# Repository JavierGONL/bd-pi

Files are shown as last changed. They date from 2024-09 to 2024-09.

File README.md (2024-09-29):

# BD-π

------------
## integrantes: 
* Kevin Javier Gonzalez Luna
* David Alejandro Montes Rodrigrez
* Rafael David Martinez Ovallos
------------

<div align='center'>
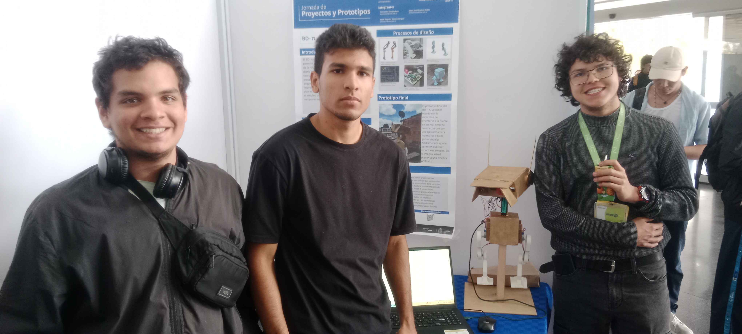
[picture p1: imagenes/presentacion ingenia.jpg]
<figure> </br>
<figcaption><b></b></figcaption></figure>
</div>

#### 🤖[wiki del proyecto](https://github.com/JavierGONL/bd-pi/wiki)🤖

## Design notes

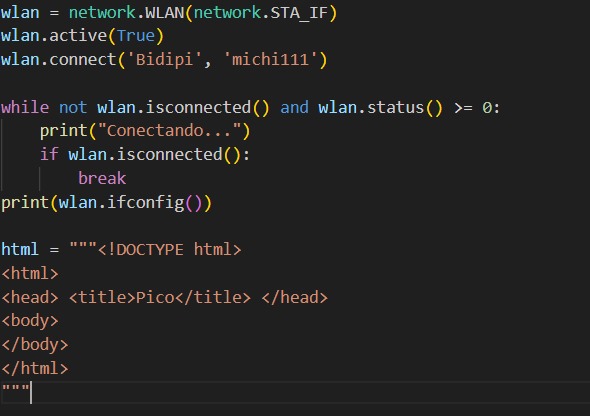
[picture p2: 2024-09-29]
imagenes/Código Wifi.jpg

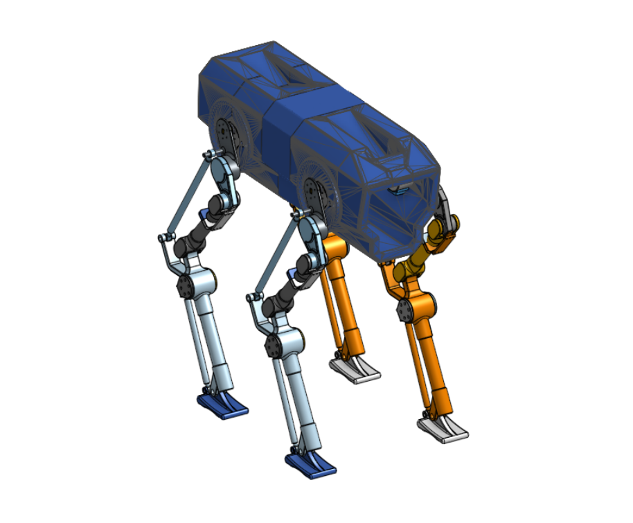
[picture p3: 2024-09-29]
imagenes/Primer modelo.png

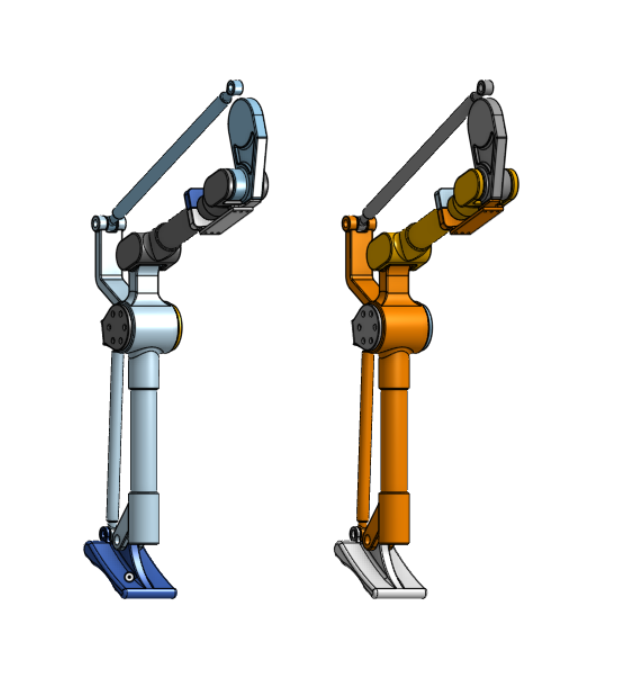
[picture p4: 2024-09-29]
imagenes/Patas Modeladas.png

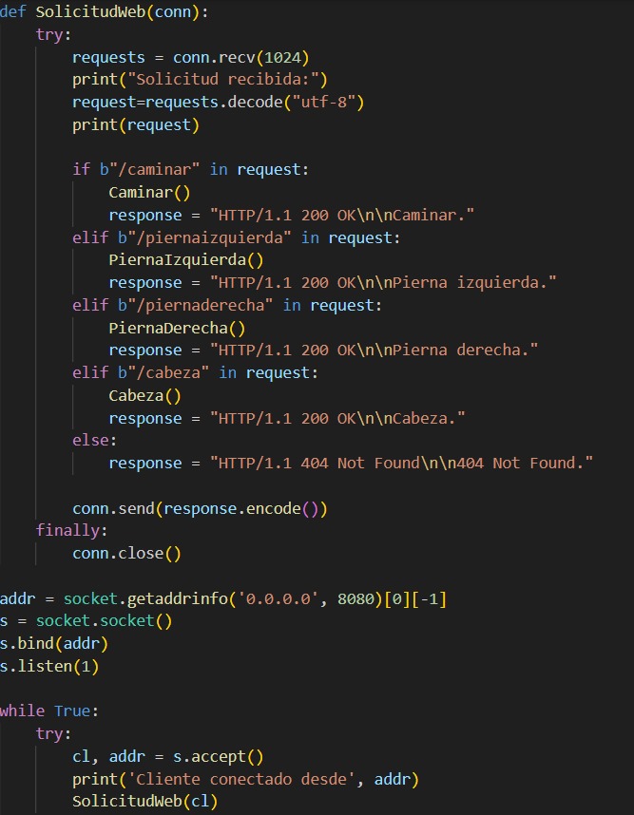
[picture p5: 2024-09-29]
imagenes/Imagen de WhatsApp 2024-09-25 a las 10.45.55_e9e9bb14.jpg

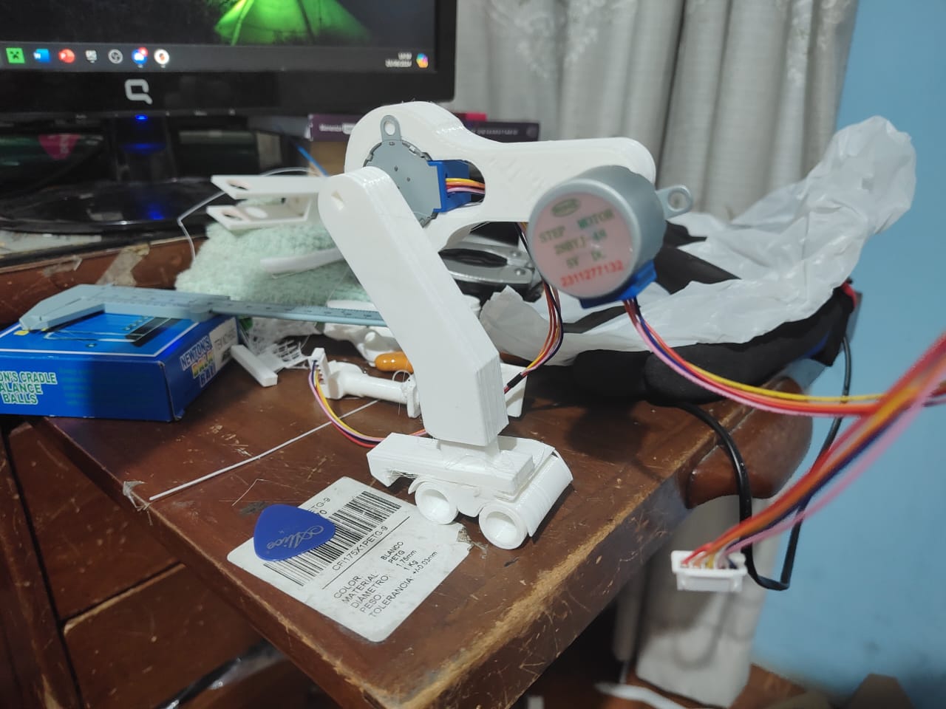
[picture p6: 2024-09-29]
imagenes/Idea Patines.jpg

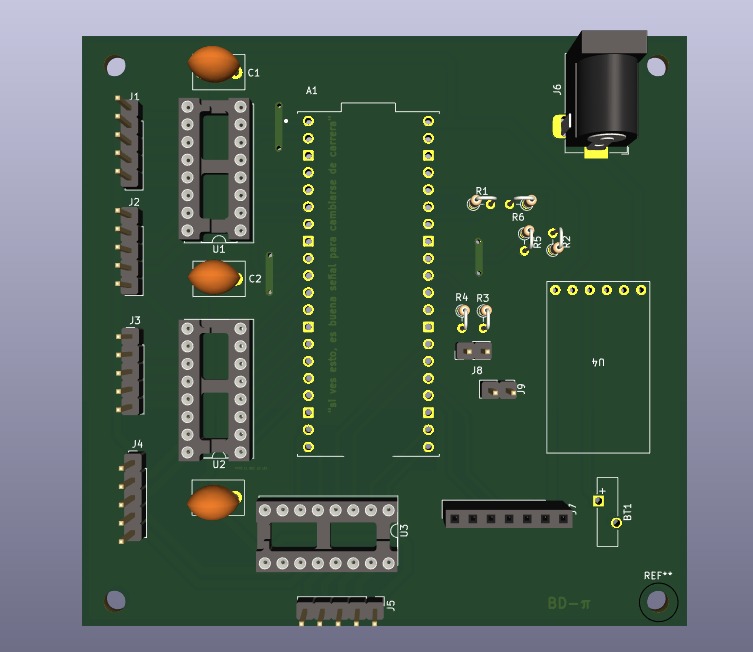
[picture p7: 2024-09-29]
imagenes/PCB 3D.jpg

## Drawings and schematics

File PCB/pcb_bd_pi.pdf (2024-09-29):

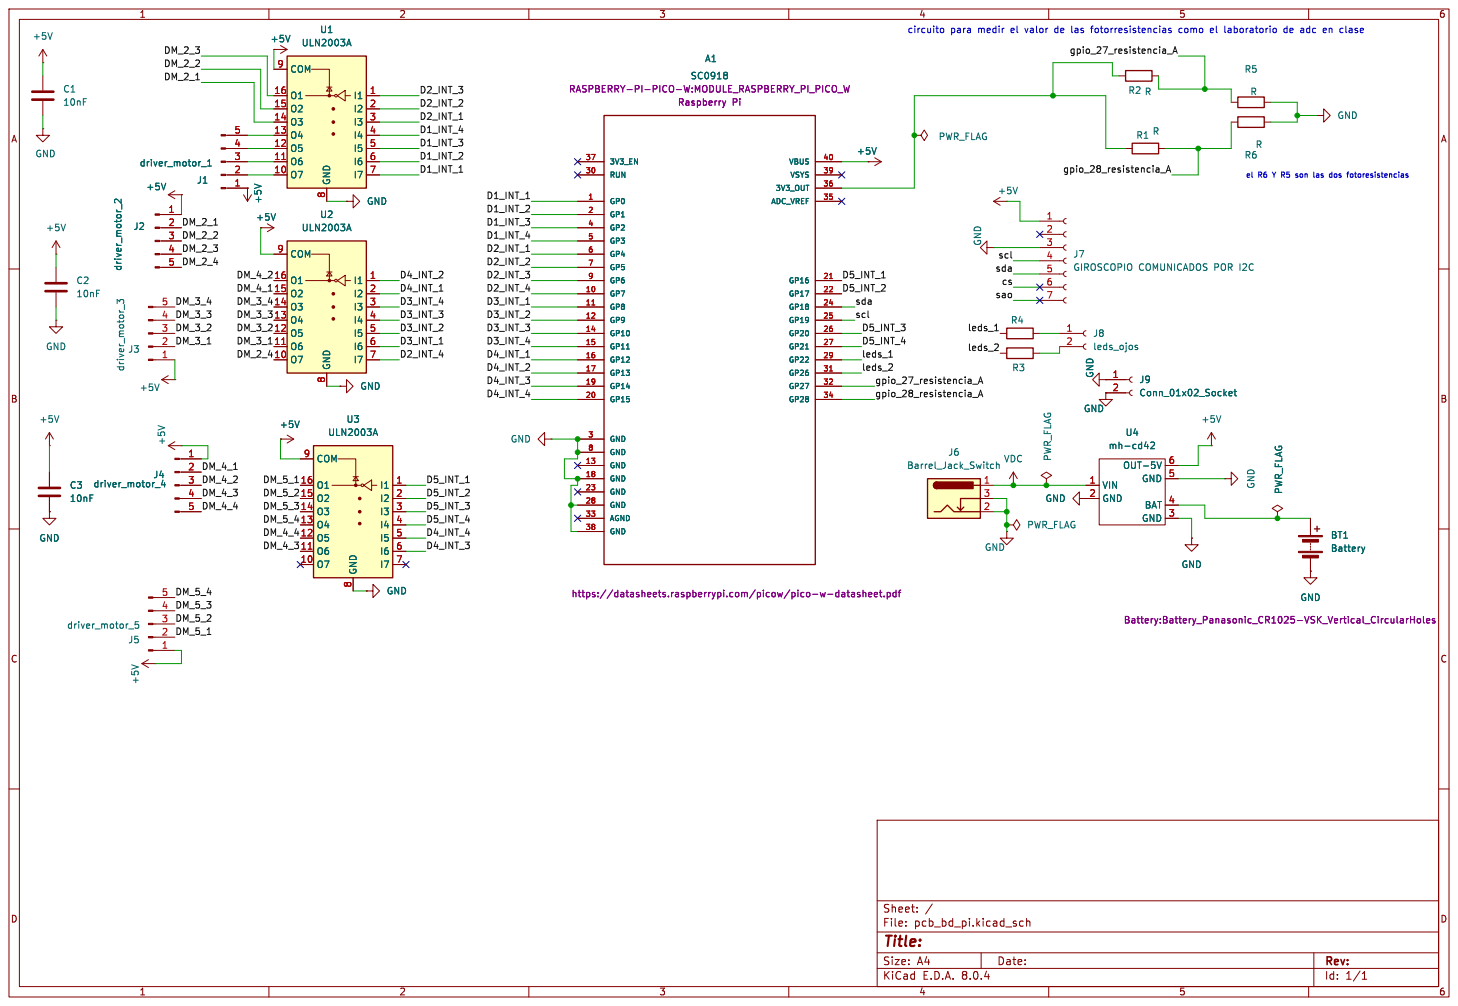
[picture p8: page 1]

Id: 1/1 Title: File: pcb_bd_pi.kicad_sch Sheet: / GND

https://datasheets.raspberrypi.com/picow/pico-w-datasheet.pdf

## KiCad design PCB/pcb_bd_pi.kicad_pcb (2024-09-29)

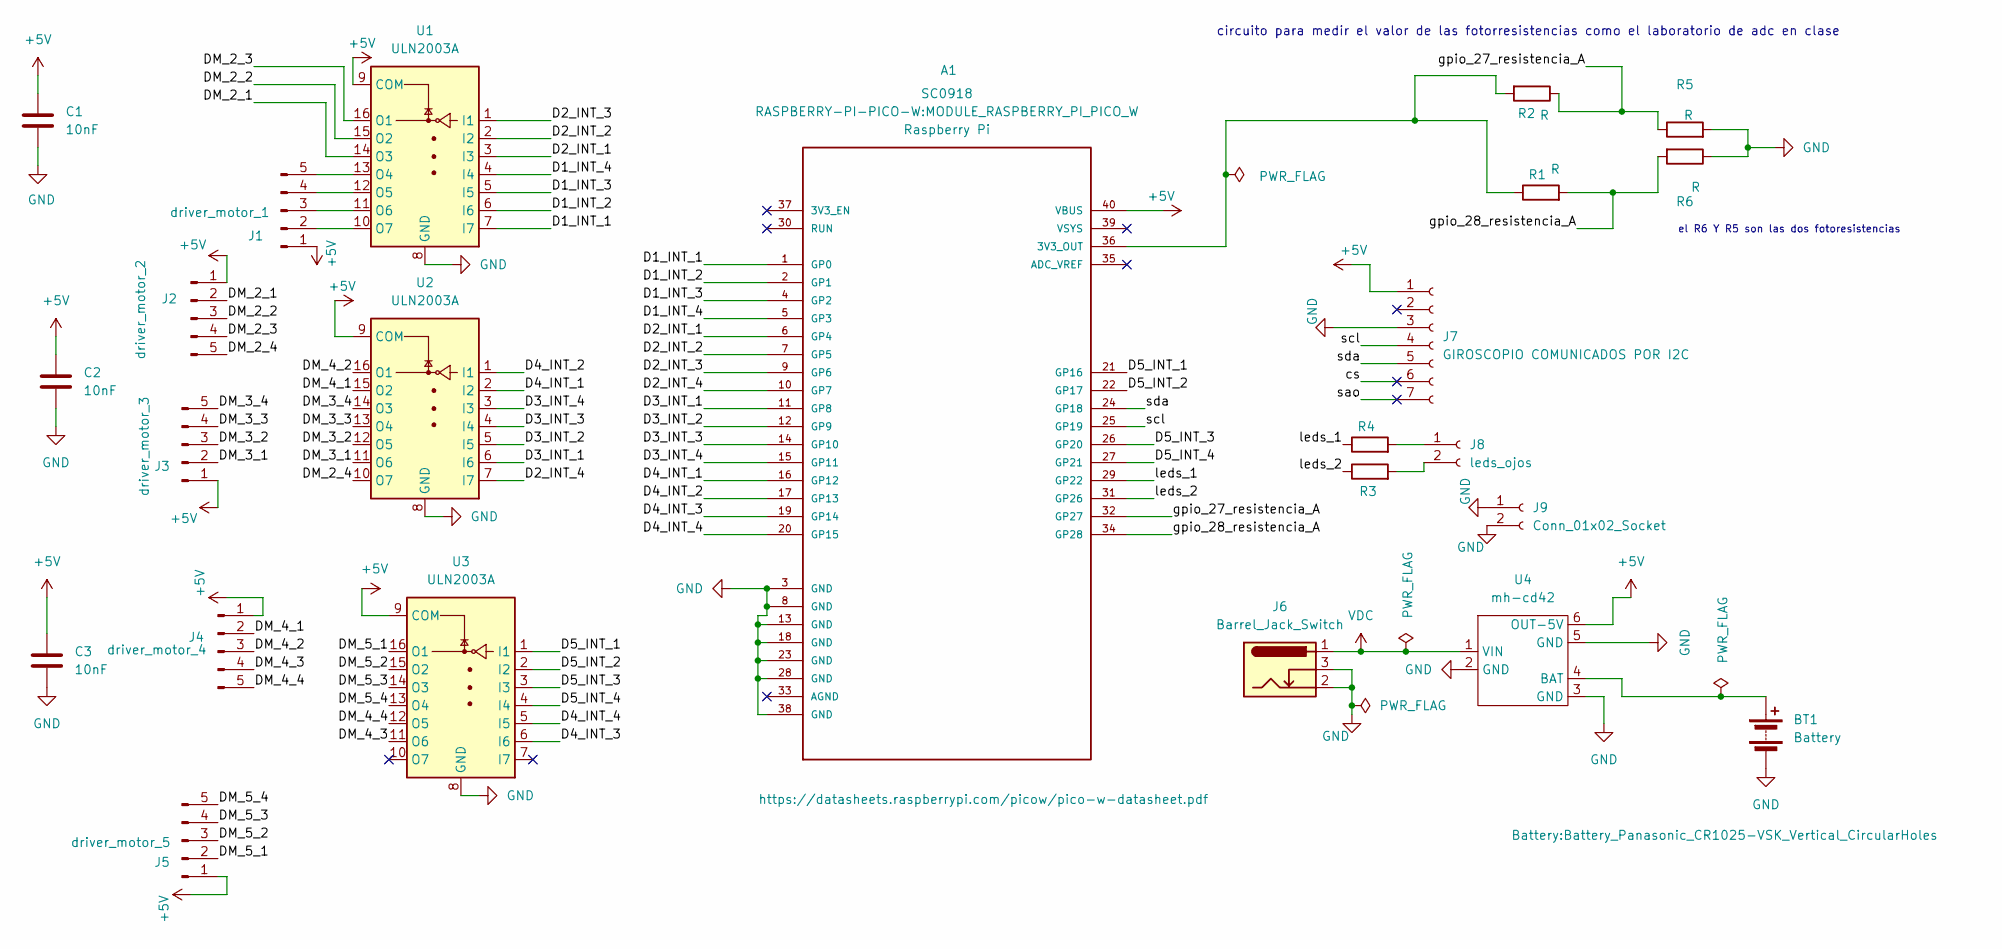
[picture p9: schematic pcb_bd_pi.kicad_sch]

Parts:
A1: SC0918; MODULE_RASPBERRY_PI_PICO_W; PARTREV 1.6
BT1: Battery; Battery_Panasonic_CR1025-VSK_Vertical_CircularHoles
C1, C2, C3: 10nF; C_Disc_D7.5mm_W5.0mm_P5.00mm
J1: driver_motor_1; PinHeader_1x05_P2.54mm_Vertical
J2: driver_motor_2; PinHeader_1x05_P2.54mm_Vertical
J3: driver_motor_3; PinHeader_1x05_P2.54mm_Vertical
J4: driver_motor_4; PinHeader_1x05_P2.54mm_Vertical
J5: driver_motor_5; PinHeader_1x05_P2.54mm_Vertical
J6: Barrel_Jack_Switch; BarrelJack_Horizontal
J7: GIROSCOPIO COMUNICADOS POR I2C; PinSocket_1x07_P2.54mm_Vertical
J8: leds_ojos; PinHeader_1x02_P2.54mm_Vertical
J9: Conn_01x02_Socket; PinHeader_1x02_P2.54mm_Vertical
R1, R2, R3, R4, R5, R6: R; R_Axial_DIN0204_L3.6mm_D1.6mm_P2.54mm_Vertical
U1, U2, U3: ULN2003A; DIP-16_W7.62mm_Socket
U4: mh-cd42

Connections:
+5V: A1.40 (VBUS), C1.1, C2.1, C3.1, J1.1, J2.1, J3.1, J4.1, J5.1, J7.1, U1.9 (COM), U2.9 (COM), U3.9 (COM), U4.6 (OUT-5V)
/D1_INT_1: A1.1 (GP0), U1.7 (I7)
/D1_INT_2: A1.2 (GP1), U1.6 (I6)
/D1_INT_3: A1.4 (GP2), U1.5 (I5)
/D1_INT_4: A1.5 (GP3), U1.4 (I4)
/D2_INT_1: A1.6 (GP4), U1.3 (I3)
/D2_INT_2: A1.7 (GP5), U1.2 (I2)
/D2_INT_3: A1.9 (GP6), U1.1 (I1)
/D2_INT_4: A1.10 (GP7), U2.7 (I7)
/D3_INT_1: A1.11 (GP8), U2.6 (I6)
/D3_INT_2: A1.12 (GP9), U2.5 (I5)
/D3_INT_3: A1.14 (GP10), U2.4 (I4)
/D3_INT_4: A1.15 (GP11), U2.3 (I3)
/D4_INT_1: A1.16 (GP12), U2.2 (I2)
/D4_INT_2: A1.17 (GP13), U2.1 (I1)
/D4_INT_3: A1.19 (GP14), U3.6 (I6)
/D4_INT_4: A1.20 (GP15), U3.5 (I5)
/D5_INT_1: A1.21 (GP16), U3.1 (I1)
/D5_INT_2: A1.22 (GP17), U3.2 (I2)
/D5_INT_3: A1.26 (GP20), U3.3 (I3)
/D5_INT_4: A1.27 (GP21), U3.4 (I4)
/DM_2_1: J2.2, U1.14 (O3)
/DM_2_2: J2.3, U1.15 (O2)
/DM_2_3: J2.4, U1.16 (O1)
/DM_2_4: J2.5, U2.10 (O7)
/DM_3_1: J3.2, U2.11 (O6)
/DM_3_2: J3.3, U2.12 (O5)
/DM_3_3: J3.4, U2.13 (O4)
/DM_3_4: J3.5, U2.14 (O3)
/DM_4_1: J4.2, U2.15 (O2)
/DM_4_2: J4.3, U2.16 (O1)
/DM_4_3: J4.4, U3.11 (O6)
/DM_4_4: J4.5, U3.12 (O5)
/DM_5_1: J5.2, U3.16 (O1)
/DM_5_2: J5.3, U3.15 (O2)
/DM_5_3: J5.4, U3.14 (O3)
/DM_5_4: J5.5, U3.13 (O4)
/cs: J7.6
/gpio_27_resistencia_A: A1.32 (GP27), R2.1, R5.1
/gpio_28_resistencia_A: A1.34 (GP28), R1.2, R6.2
/leds_1: A1.29 (GP22), R4.1
/leds_2: A1.31 (GP26), R3.1
/sao: J7.7
/scl: A1.25 (GP19), J7.4
/sda: A1.24 (GP18), J7.5
GND: A1.3 (GND), A1.8 (GND), A1.13 (GND), A1.18 (GND), A1.23 (GND), A1.28 (GND), A1.38 (GND), BT1.2 (-), C1.2, C2.2, C3.2, J6.2, J6.3, J7.3, J9.1, J9.2, R5.2, R6.1, U1.8 (GND), U2.8 (GND), U3.8 (GND), U4.2 (GND), U4.3 (GND), U4.5 (GND)
unnamed: A1.36 (3V3_OUT), R1.1, R2.2
unnamed: BT1.1 (+), U4.4 (BAT)
unnamed: J1.2, U1.10 (O7)
unnamed: J1.3, U1.11 (O6)
unnamed: J1.4, U1.12 (O5)
unnamed: J1.5, U1.13 (O4)
unnamed: J8.1, R4.2
unnamed: J8.2, R3.2
VDC: J6.1, U4.1 (VIN)

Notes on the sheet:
circuito para medir el valor de las fotorresistencias como el laboratorio de adc en clase
el R6 Y R5 son las dos fotoresistencias

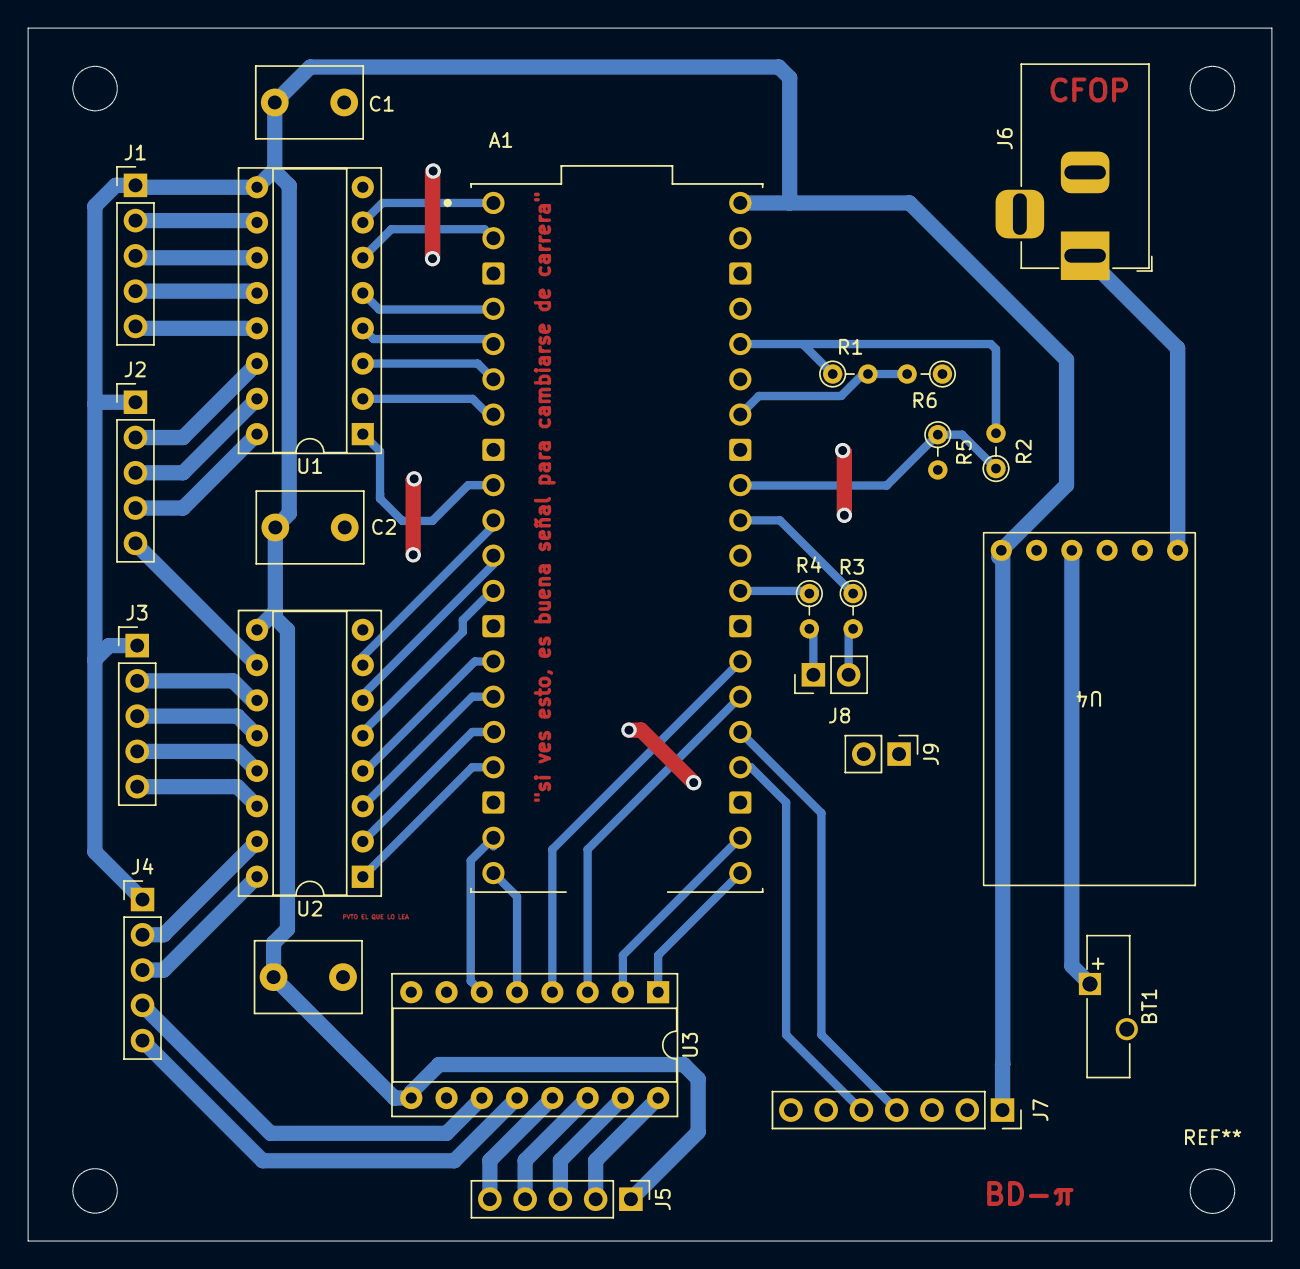
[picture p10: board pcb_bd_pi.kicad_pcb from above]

Board: 2 copper layers, 89.6 x 87.4 mm, 24 parts (0 on the bottom side), 53 nets.

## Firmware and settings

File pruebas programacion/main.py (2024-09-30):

#* disclaimer

#si se guarda este archivo como main, la comunicación entre la pico w y el pc queda interrumpida
#en algún lugar remoto de internet debe decir como solucionar esto pacíficamente
# la sugerencia personal es formatear la pico w si se quiere volver a usar



#imports
from machine import ADC, Pin, I2C
from micropython_bmi160 import bmi160 #esto se instala con gestionar paquetes en thonny
import time
import socket
#import sys
#boot.py
#primero se ejecuta el boot para conectarlo a wifi
import network
ssid = 'nombre red wifi'
password = 'contraseña red wifi'

# pines motores

pins_1= [
     Pin (0, Pin.OUT), # IN1
     Pin (1, Pin.OUT), # IN2
     Pin (2, Pin.OUT), # IN3
     Pin (3, Pin.OUT)  # IN4
     ]
pins_2=[
     Pin (4, Pin.OUT), # IN1
     Pin (5, Pin.OUT), # IN2
     Pin (6, Pin.OUT), # IN3
     Pin (7, Pin.OUT)  # IN4
     ]
pins_3=[
     Pin (8, Pin.OUT), # IN1
     Pin (9, Pin.OUT), # IN2
     Pin (10, Pin.OUT), # IN3
     Pin (11, Pin.OUT)  # IN4
     ]
pins_4=[
     Pin (16, Pin.OUT), # IN1
     Pin (17, Pin.OUT), # IN2
     Pin (20, Pin.OUT), # IN3
     Pin (21, Pin.OUT)  # IN4
     ]

# motor cabeza

pins_5=[
     Pin (12, Pin.OUT), # IN1
     Pin (13, Pin.OUT), # IN2
     Pin (14, Pin.OUT), # IN3
     Pin (15, Pin.OUT)  # IN4
     ]

# cabeza

#crear los 2 pines ADC y los leds
adc_1 = ADC(Pin(27))# resistencia izquierda
adc_2= ADC(Pin(28)) # resistencia derecha
led_1 = Pin (22, Pin.OUT)
led_2 = Pin (26, Pin.OUT)
# banderas
ir_derecha= False
ir_izquierda= False

#giroscopio
i2c = I2C(1, sda=Pin(18), scl=Pin(19))  # Correct I2C pins for RP2040
bmi = bmi160.BMI160(i2c)
bandera_equilibrio=False

#pasos motores

secuencia = [
    [1,0,0,0],
    [0,1,0,0],
    [0,0,1,0],
    [0,0,0,1]
    ]

secuencia2 = [
    [1,1,0,0],
    [0,1,1,0],
    [0,0,1,1],
    [1,0,0,1]
    ]

secuencia3 = [
    [1,0,0,0],
    [1,1,0,0],
    [0,1,0,0],
    [0,1,1,0],
    [0,0,1,0],
    [1,0,1,1],
    [0,0,0,1],
    [1,0,0,1]
    ]

#programacion motores
def paso_motor(secuencia, pins, revoluciones,invertir =False):
    revolucion_a = 0
    while True:
        if not invertir:
            for paso in secuencia:
                for i in range(len(pins)):
                    pins[i].value(paso[::-1][i])
                    time.sleep(0.001)
                    revolucion_a +=1
            if revolucion_a >= revoluciones:             
                break
        else: 
            for paso in secuencia:
                for i in range(len(pins)):
                    pins[i].value(paso[i])
                    time.sleep(0.001)
                    revolucion_a +=1
            if revolucion_a >= revoluciones:             
                break
def doble_paso_motor(secuencia, pins, pins2, revoluciones,invertir=False):
    revolucion_a = 0
    while True:
        if not invertir:
            for paso in secuencia:
                for i in range(len(pins)):
                    pins[i].value(paso[::-1][i])
                    pins2[i].value(paso[i])
                    time.sleep(0.001)
                    revolucion_a +=1
            if revolucion_a >= revoluciones:             
                break
        else: 
            for paso in secuencia:
                for i in range(len(pins)):
                    pins[i].value(paso[i])
                    pins2[i].value(paso[::-1][i])
                    time.sleep(0.001)
                    revolucion_a +=1
            if revolucion_a >= revoluciones:             
                break

def giroscopio(bmi = bmi,bandera_equilibrio = bandera_equilibrio):
    while True:
        gyrox, gyroy, gyroz = bmi.gyro
        #print(f"x:{gyrox:.2f}°/s, y:{gyroy:.2f}°/s, z{gyroz:.2f}°/s") #monitoreo
        if abs(gyrox) >=12 or abs(gyroy)>=12:
            bandera_equilibrio=True
        time.sleep(0.5)
        break
    while bandera_equilibrio:
        pasos=0
        while pasos <=100:
            doble_paso_motor(secuencia2,pins_1,pins_2,13.75,False)
            doble_paso_motor(secuencia2,pins_3,pins_4,13.75,True)
            pasos+=1
        pasos=0
        break


# funcion que calcula donde girar la cabeza
def movimiento_cabeza(adc_1,adc_2):
    intensidades_luz=[adc_1.read_u16(),adc_2.read_u16()]
    # porcentaje_d = intensidades_luz[0]*100/65535
    # porcentaje_i = intensidades_luz[1]*100/(65535-500)
    bandera_cambio = abs(intensidades_luz[0] - intensidades_luz[1]) * 100 /65535
    if intensidades_luz[0] >intensidades_luz[1] and bandera_cambio > 10:
        ir_derecha=True
        led_1.value(1)
        led_2.value(0)
        return ir_derecha
    if intensidades_luz[0] < intensidades_luz[1] and bandera_cambio > 10:
        ir_derecha=False
        led_1.value(0)
        led_2.value(1)
        return ir_derecha

#Aqui va el codigo para conectarlo a Wifi

revoluciones = 10 # 8250 una vuelta
pasos = 0


def Caminar():
    global revoluciones
    global pasos
    #print("gatito") #monitoreo
    #print(revoluciones)
    #print(pasos)
    if True:
        while True:
            paso_motor(secuencia2, pins_1, revoluciones,True)
            paso_motor(secuencia2, pins_1, revoluciones,True)
            pasos+=1
            if pasos >= 50:
                pasos = 0
                break
        while True:
            paso_motor(secuencia2, pins_2,revoluciones,True)
            paso_motor(secuencia2, pins_2,revoluciones,True)
            pasos+=1
            if pasos >= 25:
                pasos=0
                break
        while True:
            paso_motor(secuencia2, pins_1, revoluciones)
            paso_motor(secuencia2, pins_1, revoluciones)
            pasos+=1
            if pasos >= 75:
                pasos = 0
                break
        while True:
            paso_motor(secuencia2, pins_2, revoluciones)
            paso_motor(secuencia2, pins_2, revoluciones)
            pasos+=1
            if pasos >= 25:
                pasos=0
                break
        while True:
            paso_motor(secuencia2, pins_1, revoluciones,True)
            paso_motor(secuencia2, pins_1, revoluciones,True)
            pasos+=1
            if pasos >= 25:
                pasos = 0
                break
        # otra pierna
        while True:
            paso_motor(secuencia2, pins_3, revoluciones)
            paso_motor(secuencia2, pins_3, revoluciones)
            pasos+=1
            if pasos >= 50:
                pasos = 0
                break
        while True:
            paso_motor(secuencia2, pins_4, revoluciones)
            paso_motor(secuencia2, pins_4, revoluciones)
            pasos+=1
            if pasos >= 25:
                pasos=0
                break
        while True:
            paso_motor(secuencia2, pins_3, revoluciones,True)
            paso_motor(secuencia2, pins_3, revoluciones,True)
            pasos+=1
            if pasos >= 75:
                pasos = 0
                break
        while True:
            paso_motor(secuencia2, pins_4, revoluciones,True)
            paso_motor(secuencia2, pins_4, revoluciones,True)
            pasos+=1
            if pasos >= 25:
                pasos=0
                break
        while True:
            paso_motor(secuencia2, pins_3, revoluciones)
            paso_motor(secuencia2, pins_3, revoluciones)
            pasos+=1
            if pasos >= 25:
                pasos = 0
                break
            
def PiernaIzquierda():
    global revoluciones
    global pasos
    if True:
        while True:
            paso_motor(secuencia2, pins_1, revoluciones,True)
            paso_motor(secuencia2, pins_1, revoluciones,True)
            pasos+=1
            if pasos >= 50:
                pasos = 0
                break
        while True:
            paso_motor(secuencia2, pins_2,revoluciones,True)
            paso_motor(secuencia2, pins_2,revoluciones,True)
            pasos+=1
            if pasos >= 25:
                pasos=0
                break
        while True:
            paso_motor(secuencia2, pins_1, revoluciones)
            paso_motor(secuencia2, pins_1, revoluciones)
            pasos+=1
            if pasos >= 75:
                pasos = 0
                break
        while True:
            paso_motor(secuencia2, pins_2, revoluciones)
            paso_motor(secuencia2, pins_2, revoluciones)
            pasos+=1
            if pasos >= 25:
                pasos=0
                break
        while True:
            paso_motor(secuencia2, pins_1, revoluciones,True)
            paso_motor(secuencia2, pins_1, revoluciones,True)
            pasos+=1
            if pasos >= 25:
                pasos = 0
                break
def PiernaDerecha():
    # otra pierna
    global revoluciones
    global pasos
    if True:
        while True:
            paso_motor(secuencia2, pins_3, revoluciones)
            paso_motor(secuencia2, pins_3, revoluciones)
            pasos+=1
            if pasos >= 50:
                pasos = 0
                break
        while True:
            paso_motor(secuencia2, pins_4, revoluciones)
            paso_motor(secuencia2, pins_4, revoluciones)
            pasos+=1
            if pasos >= 25:
                pasos=0
                break
        while True:
            paso_motor(secuencia2, pins_3, revoluciones,True)
            paso_motor(secuencia2, pins_3, revoluciones,True)
            pasos+=1
            if pasos >= 75:
                pasos = 0
                break
        while True:
            paso_motor(secuencia2, pins_4, revoluciones,True)
            paso_motor(secuencia2, pins_4, revoluciones,True)
            pasos+=1
            if pasos >= 25:
                pasos=0
                break
        while True:
            paso_motor(secuencia2, pins_3, revoluciones)
            paso_motor(secuencia2, pins_3, revoluciones)
            pasos+=1
            if pasos >= 25:
                pasos = 0
                break
def Cabeza():
    global revoluciones
    global pasos
    while True: # movimiento de la cabeza
            revolucion_b = 0
            movimiento = movimiento_cabeza(adc_1,adc_2)
            paso_motor(secuencia2, pins_5, revoluciones,movimiento)
            pasos +=1
            if pasos>= 500:
                break
                
def simulacion():
    global revoluciones
    global pasos
    pos_inicio = True
    if True:
        if pos_inicio:
            # movimiento piernas
            while True:
                movimiento = movimiento_cabeza(adc_1,adc_2)
                paso_motor(secuencia2, pins_1, revoluciones,True)
                paso_motor(secuencia2, pins_5, revoluciones,movimiento)
                paso_motor(secuencia2, pins_1, revoluciones,True)
                pasos+=1
                if pasos >= 50:
                    pasos = 0
                    break
            while True:
                movimiento = movimiento_cabeza(adc_1,adc_2)
                paso_motor(secuencia2, pins_2,revoluciones,True)
                paso_motor(secuencia2, pins_2,revoluciones,True)
                pasos+=1
                if pasos >= 25:
                    pasos=0
                    break
            while True:
                movimiento = movimiento_cabeza(adc_1,adc_2)
                paso_motor(secuencia2, pins_1, revoluciones)
                paso_motor(secuencia2, pins_1, revoluciones)
                pasos+=1
                if pasos >= 75:
                    pasos = 0
                    break
            while True:
                movimiento = movimiento_cabeza(adc_1,adc_2)
                paso_motor(secuencia2, pins_2, revoluciones)
                paso_motor(secuencia2, pins_2, revoluciones)
                pasos+=1
                if pasos >= 25:
                    pasos=0
                    break
            while True:
                movimiento = movimiento_cabeza(adc_1,adc_2)
                paso_motor(secuencia2, pins_1, revoluciones,True)
                paso_motor(secuencia2, pins_1, revoluciones,True)
                pasos+=1
                if pasos >= 25:
                    pasos = 0
                    break
            # otra pierna
            while True:
                movimiento = movimiento_cabeza(adc_1,adc_2)
                paso_motor(secuencia2, pins_3, revoluciones)
                paso_motor(secuencia2, pins_3, revoluciones)
                pasos+=1
                if pasos >= 50:
                    pasos = 0
                    break
            while True:
                movimiento = movimiento_cabeza(adc_1,adc_2)
                paso_motor(secuencia2, pins_4, revoluciones)
                paso_motor(secuencia2, pins_4, revoluciones)
                pasos+=1
                if pasos >= 25:
                    pasos=0
                    break
            while True:
                movimiento = movimiento_cabeza(adc_1,adc_2)
                paso_motor(secuencia2, pins_3, revoluciones,True)
                paso_motor(secuencia2, pins_3, revoluciones,True)
                pasos+=1
                if pasos >= 75:
                    pasos = 0
                    break
            while True:
                movimiento = movimiento_cabeza(adc_1,adc_2)
                paso_motor(secuencia2, pins_4, revoluciones,True)
                paso_motor(secuencia2, pins_4, revoluciones,True)
                pasos+=1
                if pasos >= 25:
                    pasos=0
                    break
            while True:
                movimiento = movimiento_cabeza(adc_1,adc_2)
                paso_motor(secuencia2, pins_3, revoluciones)
                paso_motor(secuencia2, pins_3, revoluciones)
                pasos+=1
                if pasos >= 25:
                    pasos = 0
                    break
            
def conectar():
    red = network.WLAN(network.STA_IF)
    red.active(True)
    red.connect(ssid, password)
    while red.isconnected() == False:
        print('Conectando ...')
        time.sleep(1)
    ip = red.ifconfig()[0]
    print(f'Conectado con IP: {ip}')
    return ip
    
def open_socket(ip):
    address = (ip, 80)
    connection = socket.socket()
    connection.bind(address)
    connection.listen(1)
    return connection


def serve(connection):
    while True:
        cliente = connection.accept()[0]
        peticion = cliente.recv(1024)
        peticion = str(peticion)
        try:
            peticion = peticion.split()[1]
        except IndexError:
            pass
        if peticion == '/caminar':
            Caminar()
            response = "HTTP/1.1 200 OK\n\nCaminar."
        elif peticion =='/piernaizquierda':
            PiernaIzquierda()
            response = "HTTP/1.1 200 OK\n\nPierna izquierda."
        elif peticion =='/piernaderecha':
            PiernaDerecha()
            response = "HTTP/1.1 200 OK\n\nPierna derecha."
        elif peticion =='/cabeza':
            Cabeza()
            response = "HTTP/1.1 200 OK\n\nCabeza."
        elif peticion =='/simulacion':
            simulacion()
            response = "HTTP/1.1 200 OK\n\nsimulacion."
        cliente.close()

try:
    ip = conectar()
    connection = open_socket(ip)
    serve(connection)
except:
    machine.reset()
    
# disclaimer 2:

#si se guarda este archivo como main, la comunicación entre la pico w y el pc queda interrumpida
#en algún lugar remoto de internet debe decir como solucionar esto pacíficamente
# la sugerencia personal es formatear la pico w si se quiere volver a usar

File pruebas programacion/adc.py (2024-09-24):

from machine import ADC, Pin
import time
adc_1 = ADC(Pin(28))# resistencia izquierda #crear los 2 pines ADC
adc_2= ADC(Pin(27)) # resistencia derecha 
ir_derecha= False
ir_izquierda= False
while True: #inciar el bucle
    intensidades_luz=[adc_1.read_u16(),adc_2.read_u16()]
    print(intensidades_luz)
    if intensidades_luz[0] >intensidades_luz[1]:
        ir_izquierda=False
        ir_derecha=True
        print("derecha") #indicar que la pata que se activa es la derecha
    if intensidades_luz[0] < intensidades_luz[1]:
        ir_derecha=False
        ir_izquierda=True
        print("izquierda")
    time.sleep(0.5)

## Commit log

2024-09-24 Create componentes principales de la pcb.jfif
2024-09-24 Create PCB con los componentes principales v2.jfif
2024-09-24 Create PCB con los componentes principales.jfif
2024-09-24 Create PCB con los componentes soldados.jfif
2024-09-24 Create PCB soldada parte trasera.jfif
2024-09-24 Create prueba de funcionamiento v1.mp4
2024-09-24 Create exposición de funciones.py
2024-09-25 Create decodificador de bits copilot.py
